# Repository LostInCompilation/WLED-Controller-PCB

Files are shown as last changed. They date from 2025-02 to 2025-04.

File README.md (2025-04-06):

# WLED Controller (ESP32) - 4 Channels - Current and power monitoring

### ❤️💰 Donation - Help a student pay rent

<a href="https://buymeacoffee.com/lostincompilation" target="_blank">Buy Me A Coffee</a>

## You can buy the PCB in my shop
Buy the PCB here (available in 2 days): https://buymeacoffee.com/lostincompilation

## Features
- 4 Channels
    - Max 25A total
    - Max 10A per channel
- Every channel has _independent_ current, power and voltage monitoring (using INA219)
- Sending power monitoring data to HomeAssistant via MQTT
- Relay for cutting power to LED-strips
- Touch surface on PCB (next to LED) usable as custom button
- SMD-1206 parts for easy hand soldering
- Reverse polarity protection
- Seperate 3.3V low noise voltage regulator for audio section
- _**Optional:** INMP441 I2S Microphone with low noise power supply_
- _**Optional:** Line-In Audio with extension board (I2S ADC: PCM1808)_

## Usermod
This board requires a usermod for WLED for full support of all features including power monitoring.

_**NOTE:** The usermod is currently in development and will be uploaded to thtis repository._

## 3D Board view
<p align="center" width="100%">
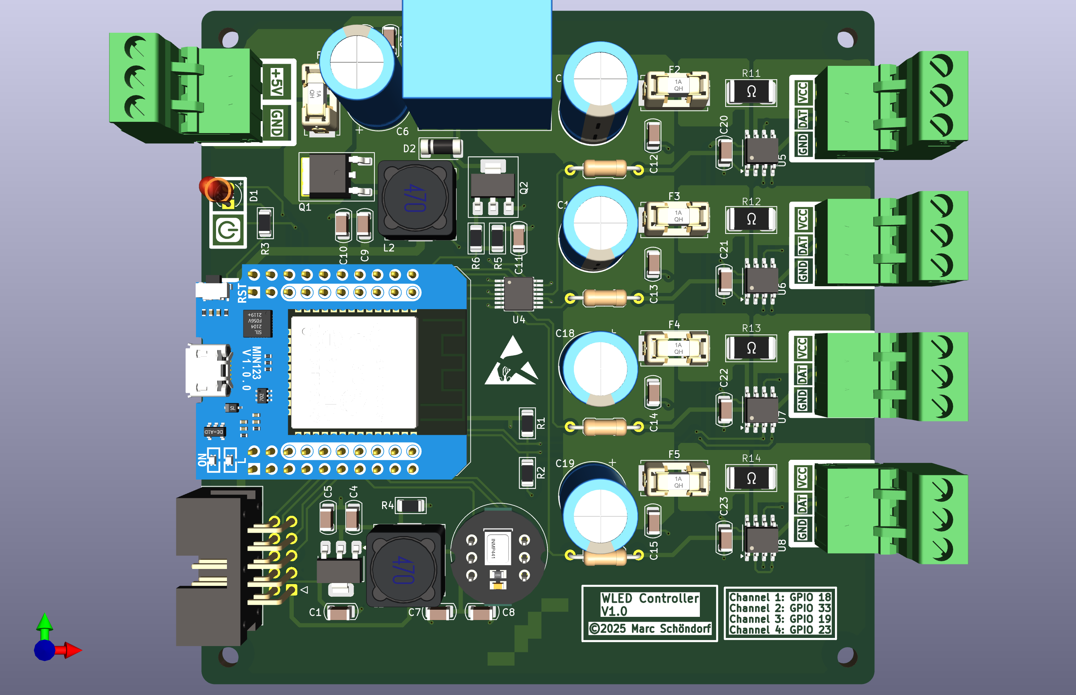
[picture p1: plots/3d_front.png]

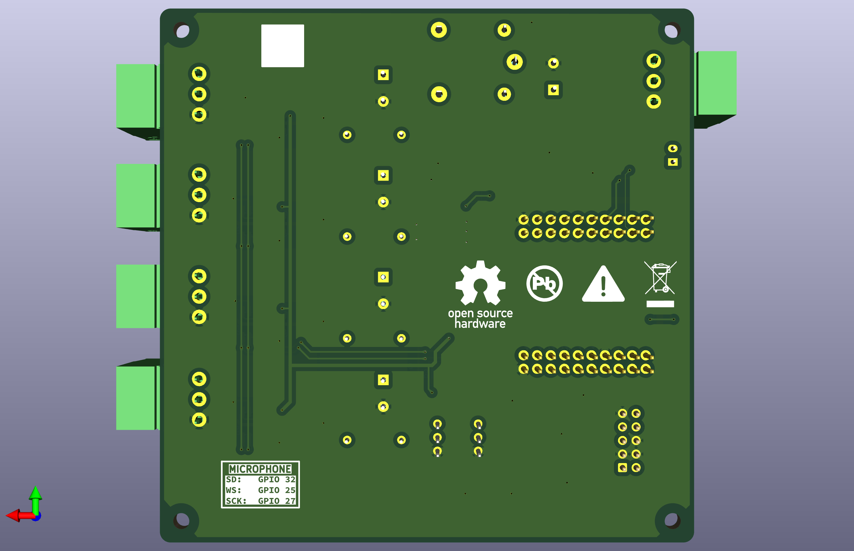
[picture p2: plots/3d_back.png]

</p>

## Board
<p align="center" width="100%">
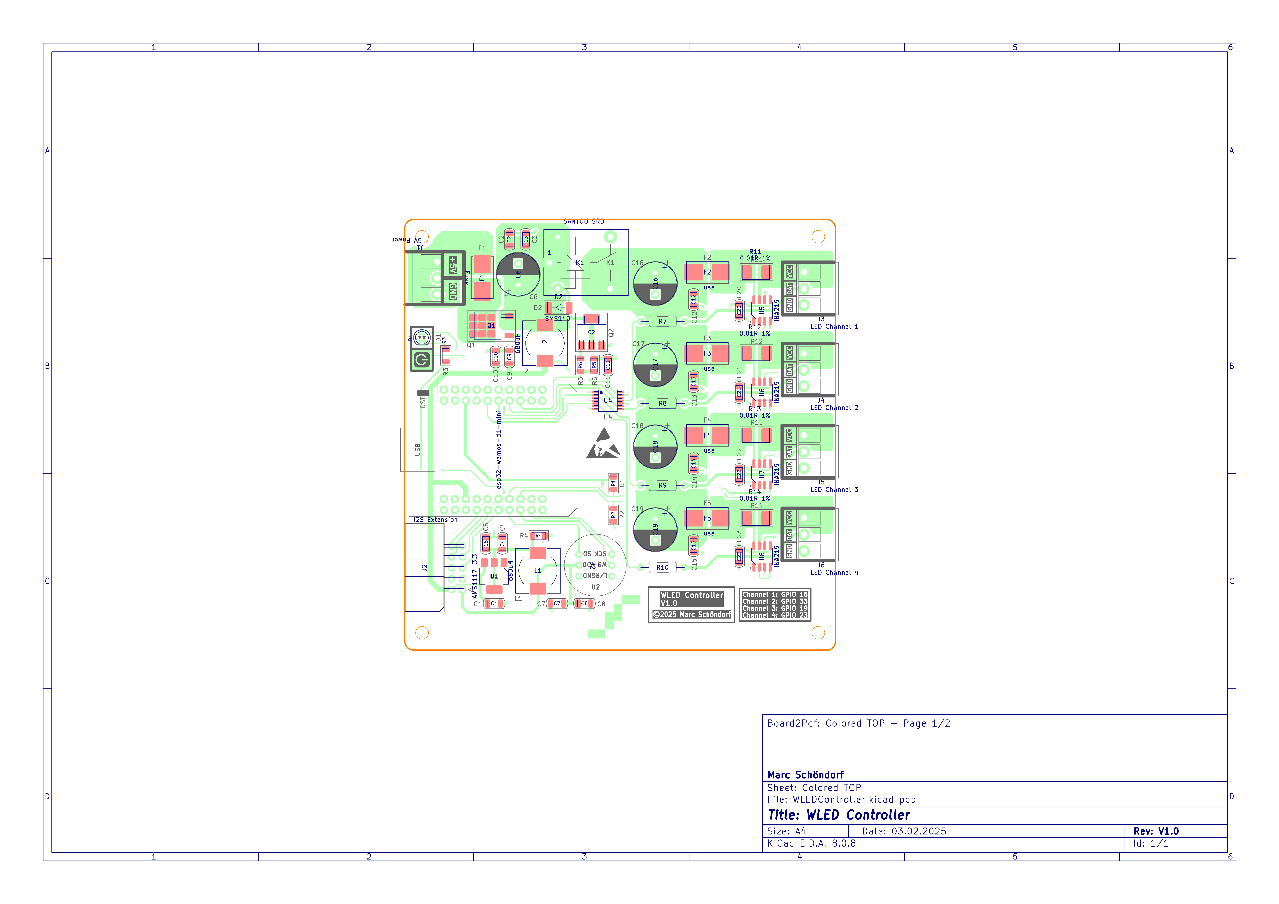
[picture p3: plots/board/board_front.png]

</p>

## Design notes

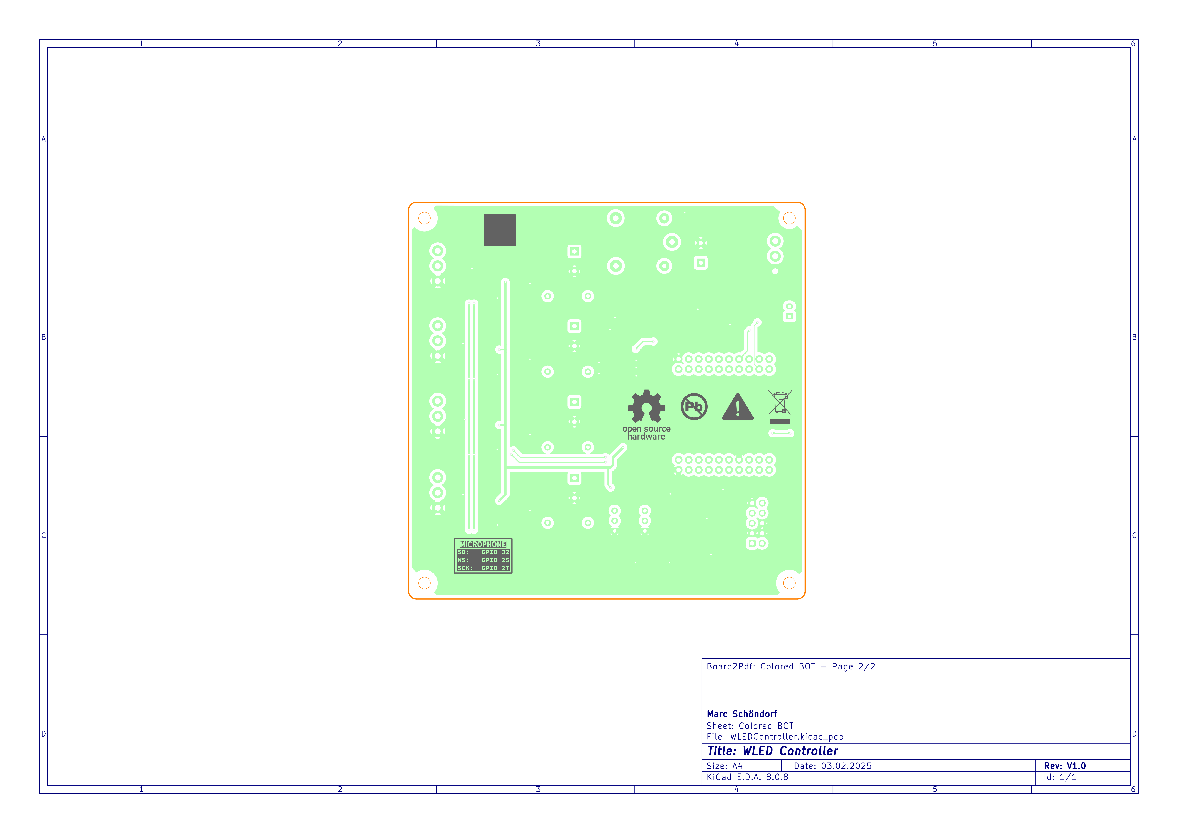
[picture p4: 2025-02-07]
plots/board/board_back.png

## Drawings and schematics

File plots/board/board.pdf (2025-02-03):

F1 | R¹ | F2 1 | 2 | 3 | 4 | 5 | 6 1 | 2 | 3 | 4 | 5 | 6 ABCD | ABCD Date: 03.02.2025 KiCad | E.D.A. 8.0.8 Size: A4 | Rev: V1.0

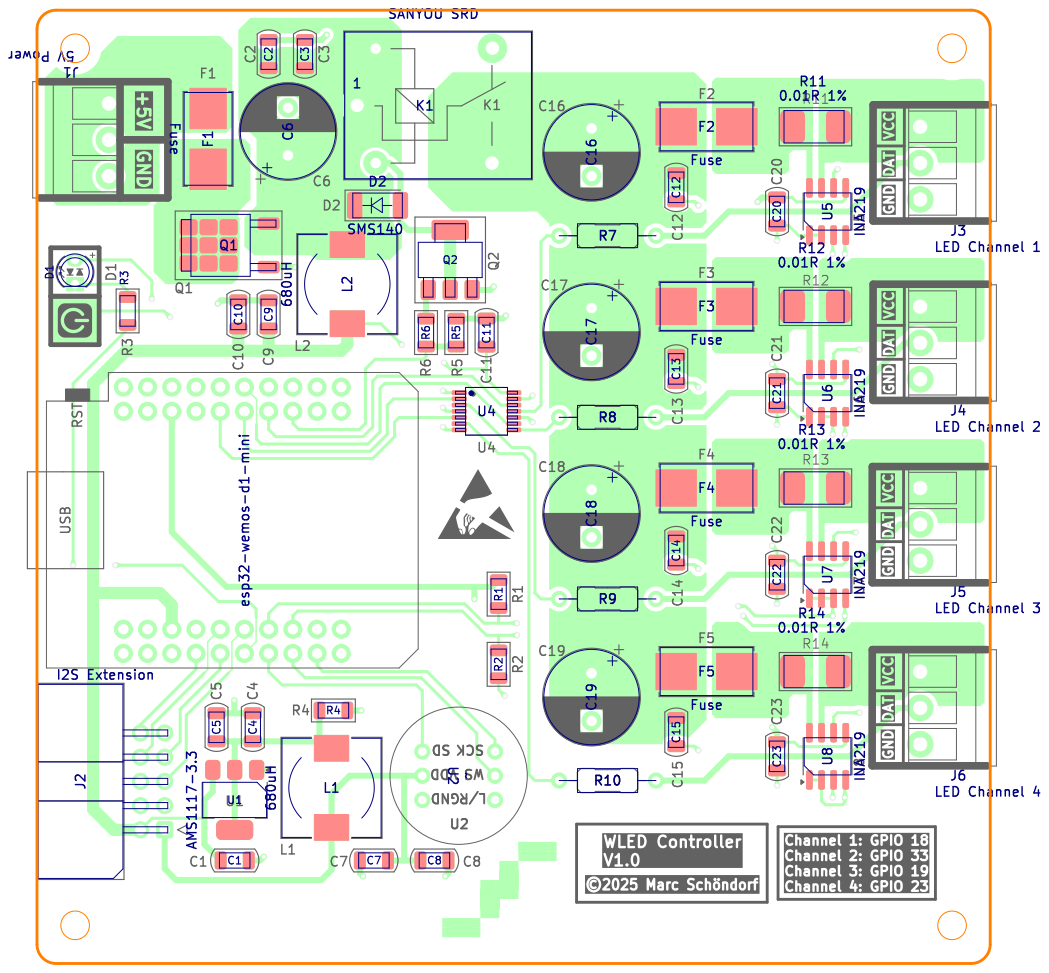
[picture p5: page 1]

1 | 2 | 3 | 4 | 5 | 6

A

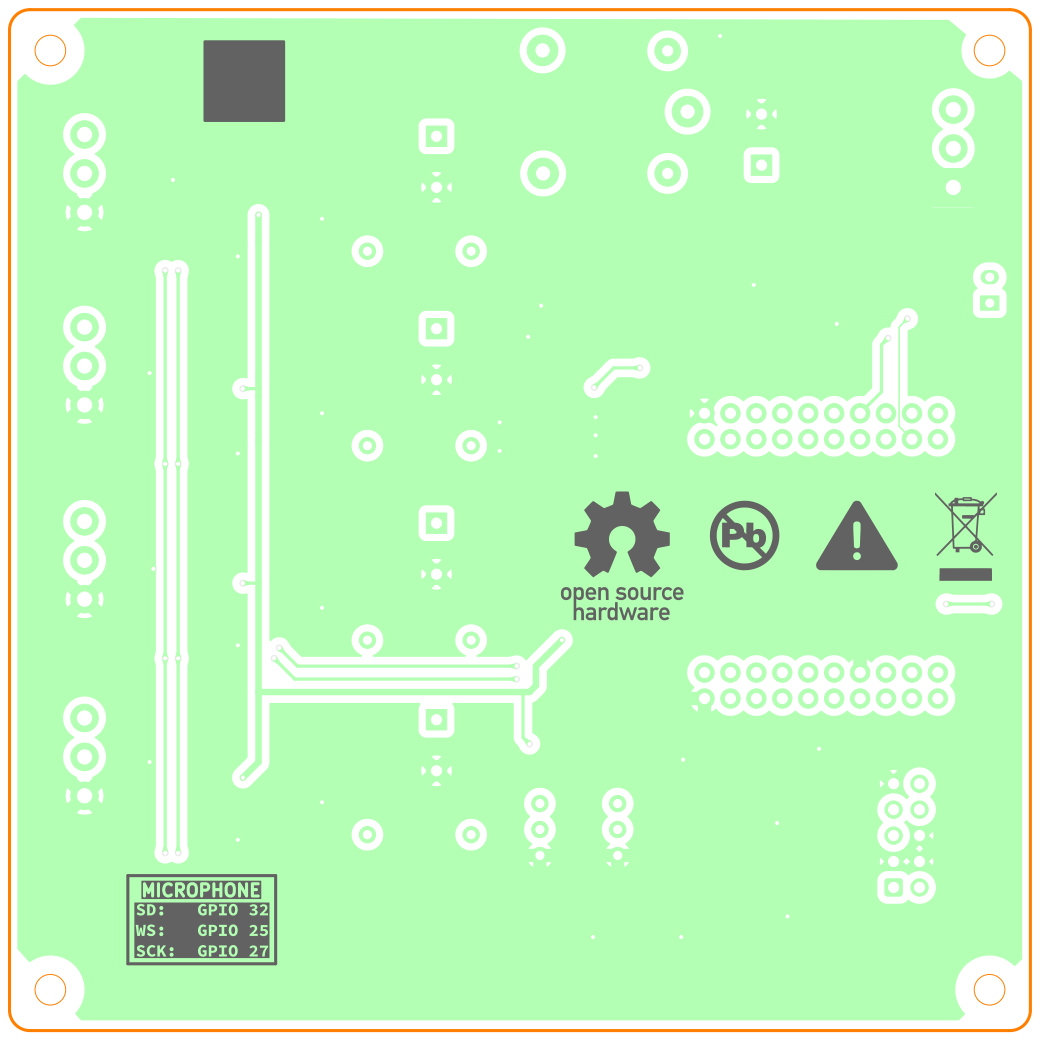
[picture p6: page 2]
D Date: 03.02.2025 KiCad; E.D.A. 8.0.8 Size: A4; Rev: V1.0; Id: 1/1 Title: WLED Controller File: WLEDController.kicad_pcb Sheet: Colored; BOT Marc þÿSchöndorf Board2Pdf:; Colored; BOT -; Page 2/2

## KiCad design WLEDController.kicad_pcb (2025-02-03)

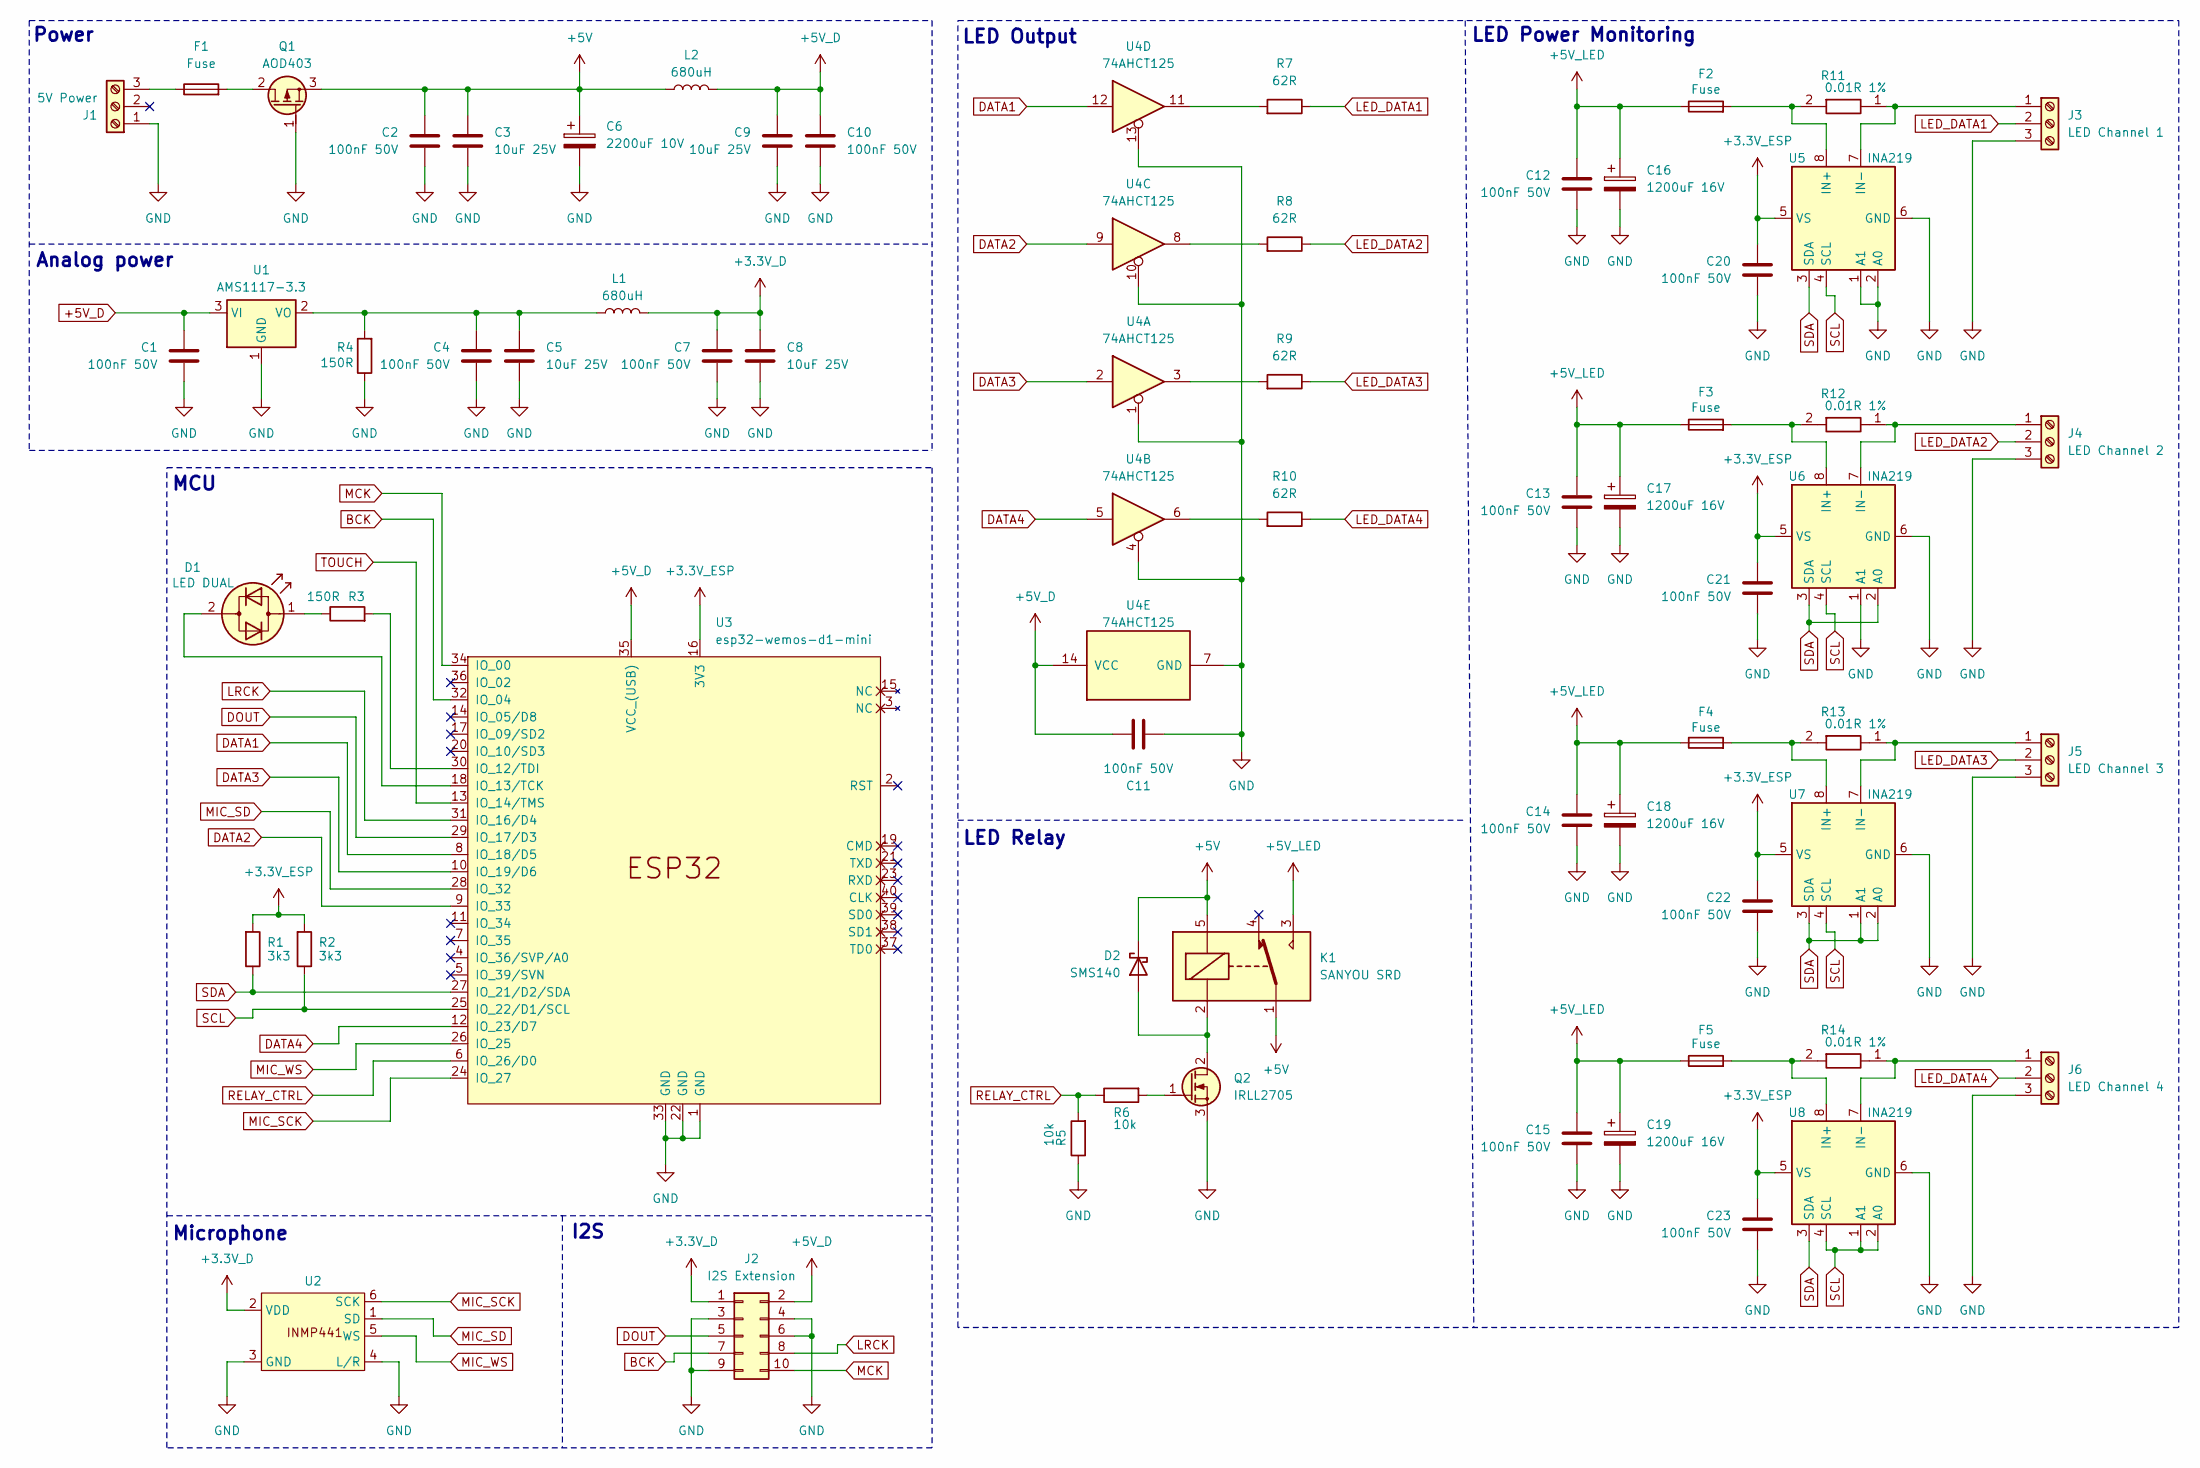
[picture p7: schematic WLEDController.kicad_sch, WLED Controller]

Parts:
C1, C2, C4, C7, C10, C11, C12, C13, C14, C15, C20, C21, C22, C23: 100nF 50V; C_1206_3216Metric
C3, C5, C8, C9: 10uF 25V; C_1206_3216Metric
C6: 2200uF 10V; CP_Radial_D10.0mm_P5.00mm
C16, C17, C18, C19: 1200uF 16V; CP_Radial_D10.0mm_P5.00mm
D1: LED DUAL; LED_D3.0mm_BiDir
D2: SMS140; D_MELF
F1, F2, F3, F4, F5: Fuse; Fuseholder_Littelfuse_Nano2_154x
J1: 5V Power; ScrewPlug_3P_Vertical
J2: I2S Extension; IDC-Header_2x05_P2.54mm_Horizontal
J3: LED Channel 1; ScrewPlug_3P_Vertical
J4: LED Channel 2; ScrewPlug_3P_Vertical
J5: LED Channel 3; ScrewPlug_3P_Vertical
J6: LED Channel 4; ScrewPlug_3P_Vertical
K1: SANYOU SRD; Relay_SPDT_SANYOU_SRD_Series_Form_C
L1, L2: 680uH; L_10.4x10.4_H4.8
Q1: AOD403; TO-252-2
Q2: IRLL2705; SOT-223-3_TabPin2
R1, R2: 3k3; R_1206_3216Metric
R3, R4: 150R; R_1206_3216Metric
R5, R6: 10k; R_1206_3216Metric
R7, R8, R9, R10: 62R; R_Axial_DIN0207_L6.3mm_D2.5mm_P10.16mm_Horizontal
R11, R12, R13, R14: 0.01R 1%; 2512_Shunt
U1: AMS1117-3.3; SOT-223-3_TabPin2
U2: INMP441_Module
U3: esp32-wemos-d1-mini
U4: 74AHCT125; TSSOP-14_4.4x5mm_P0.65mm
U5, U6, U7, U8: INA219; SOIC-8_3.9x4.9mm_P1.27mm

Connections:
+3.3V_D: C7.1, C8.1, J2.1, L1.2, U2.2 (VDD)
+3.3V_ESP: C20.1, C21.1, C22.1, C23.1, R1.1, R2.1, U3.16 (3V3), U5.5 (VS), U6.5 (VS), U7.5 (VS), U8.5 (VS)
+5V: C2.1, C3.1, C6.1, D2.1 (K), K1.1, K1.5, L2.1, Q1.3 (S)
+5V_D: C1.1, C9.1, C10.1, C11.2, J2.2, L2.2, U1.3 (VI), U3.35 (VCC_(USB)), U4.14 (VCC)
+5V_LED: C12.1, C13.1, C14.1, C15.1, C16.1, C17.1, C18.1, C19.1, F2.1, F3.1, F4.1, F5.1, K1.3
BCK: J2.7, U3.32 (IO_04)
DATA1: U3.8 (IO_18/D5), U4.12
DATA2: U3.9 (IO_33), U4.9
DATA3: U3.10 (IO_19/D6), U4.2
DATA4: U3.12 (IO_23/D7), U4.5
DOUT: J2.5, U3.29 (IO_17/D3)
GND: C1.2, C2.2, C3.2, C4.2, C5.2, C6.2, C7.2, C8.2, C9.2, C10.2, C11.1, C12.2, C13.2, C14.2, C15.2, C16.2, C17.2, C18.2, C19.2, C20.2, C21.2, C22.2, C23.2, J1.1, J2.3, J2.4, J2.6, J2.9, J3.3, J4.3, J5.3, J6.3, Q1.1 (G), Q2.3 (S), R4.2, R5.2, U1.1 (GND), U2.3 (GND), U2.4 (L/R), U3.1 (GND), U3.22 (GND), U3.33 (GND), U4.1, U4.4, U4.7 (GND), U4.10, U4.13, U5.1 (A1), U5.2 (A0), U5.6 (GND), U6.1 (A1), U6.6 (GND), U7.6 (GND), U8.6 (GND)
LED_DATA1: J3.2, R7.2
LED_DATA2: J4.2, R8.2
LED_DATA3: J5.2, R9.2
LED_DATA4: J6.2, R10.2
LRCK: J2.8, U3.31 (IO_16/D4)
MCK: J2.10, U3.34 (IO_00)
MIC_SCK: U2.6 (SCK), U3.24 (IO_27)
MIC_SD: U2.1 (SD), U3.28 (IO_32)
MIC_WS: U2.5 (WS), U3.26 (IO_25)
unnamed: D1.2 (AK), U3.18 (IO_13/TCK)
unnamed: D1.1 (KA), R3.2
unnamed: D2.2 (A), K1.2, Q2.2 (D)
unnamed: F1.1, J1.3
unnamed: J3.1, R11.1, U5.7 (IN-)
unnamed: J4.1, R12.1, U6.7 (IN-)
unnamed: J5.1, R13.1, U7.7 (IN-)
unnamed: J6.1, R14.1, U8.7 (IN-)
unnamed: F1.2, Q1.2 (D)
unnamed: Q2.1 (G), R6.1
unnamed: R7.1, U4.11
unnamed: R8.1, U4.8
unnamed: R9.1, U4.3
unnamed: R10.1, U4.6
unnamed: C4.1, C5.1, L1.1, R4.1, U1.2 (VO)
unnamed: R3.1, U3.30 (IO_12/TDI)
unnamed: F2.2, R11.2, U5.8 (IN+)
unnamed: F3.2, R12.2, U6.8 (IN+)
unnamed: F4.2, R13.2, U7.8 (IN+)
unnamed: F5.2, R14.2, U8.8 (IN+)
RELAY_CTRL: R5.1, R6.2, U3.6 (IO_26/D0)
SCL: R2.2, U3.25 (IO_22/D1/SCL), U5.4 (SCL), U6.4 (SCL), U7.4 (SCL), U8.1 (A1), U8.2 (A0), U8.4 (SCL)
SDA: R1.2, U3.27 (IO_21/D2/SDA), U5.3 (SDA), U6.2 (A0), U6.3 (SDA), U7.1 (A1), U7.2 (A0), U7.3 (SDA), U8.3 (SDA)
TOUCH: U3.13 (IO_14/TMS)

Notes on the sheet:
I2S
LED Relay
Analog power
Power
MCU
LED Power Monitoring
LED Output
Microphone

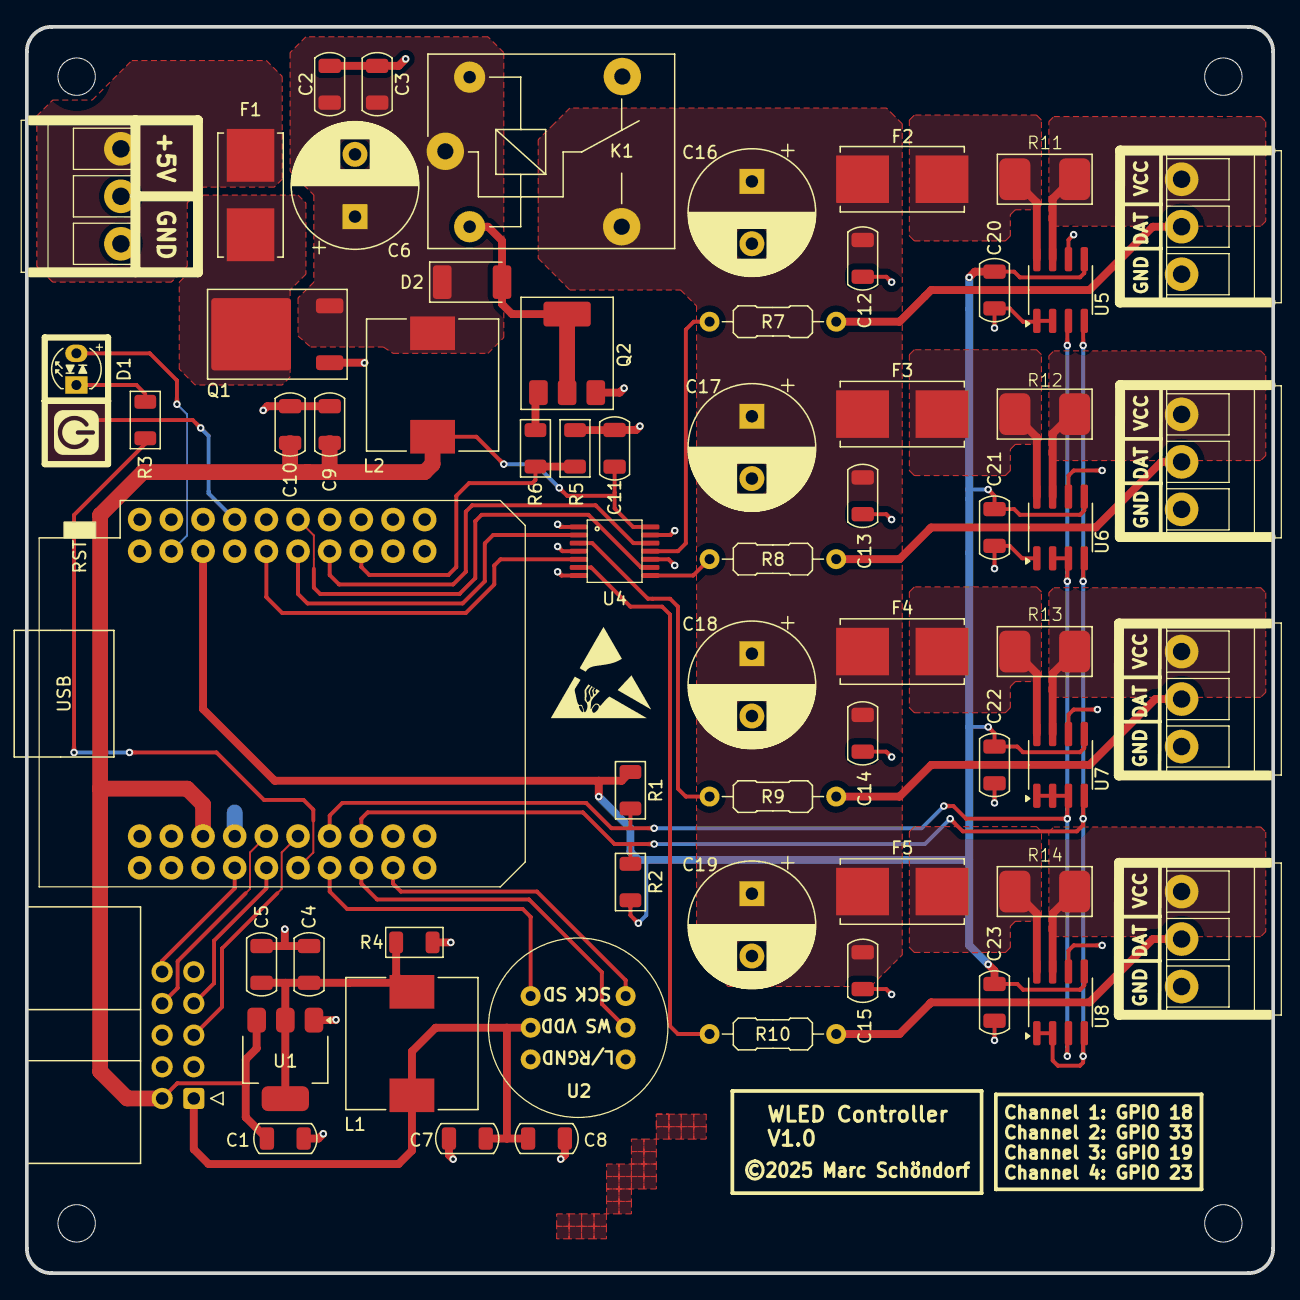
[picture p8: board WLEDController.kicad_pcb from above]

Board: 2 copper layers, 100.0 x 100.0 mm, 63 parts (0 on the bottom side), 44 nets.

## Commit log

2025-02-03 Added Gerber
2025-02-03 Added Touch sensor
    [WLEDController-B_Cu.gbr, WLEDController-B_Mask.gbr, WLEDController-B_Paste.gbr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]
2025-02-03 Gerber zip

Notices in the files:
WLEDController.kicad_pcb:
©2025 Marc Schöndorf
